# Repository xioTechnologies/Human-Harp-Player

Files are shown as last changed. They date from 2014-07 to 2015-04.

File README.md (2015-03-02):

Human-Harp-Player
=================

The Human Harp Player is a music controller based on interaction with an extendible cord under constant tension.  The Player provides measurements of the cord: extension, velocity, angle (azimuth and elevation) and angular rate (for detecting plucks).  The Player incorporates an [x-OSC](http://www.x-io.co.uk/x-osc/) to interface to host software via Wi-Fi.

Counts vary between 7800 counts/m and 1000 counts/m when fully extended, average = 8900.

See [Human Harp](http://humanharp.org/) for more information about the project.

PCB
---

The PCB was designed in [EAGLE Version 6.6](http://www.cadsoftusa.com/).  It was fabricated by [OSH Park](https://oshpark.com/) and is available to [purchase on their site](https://oshpark.com/shared_projects/F7BSWUvG).

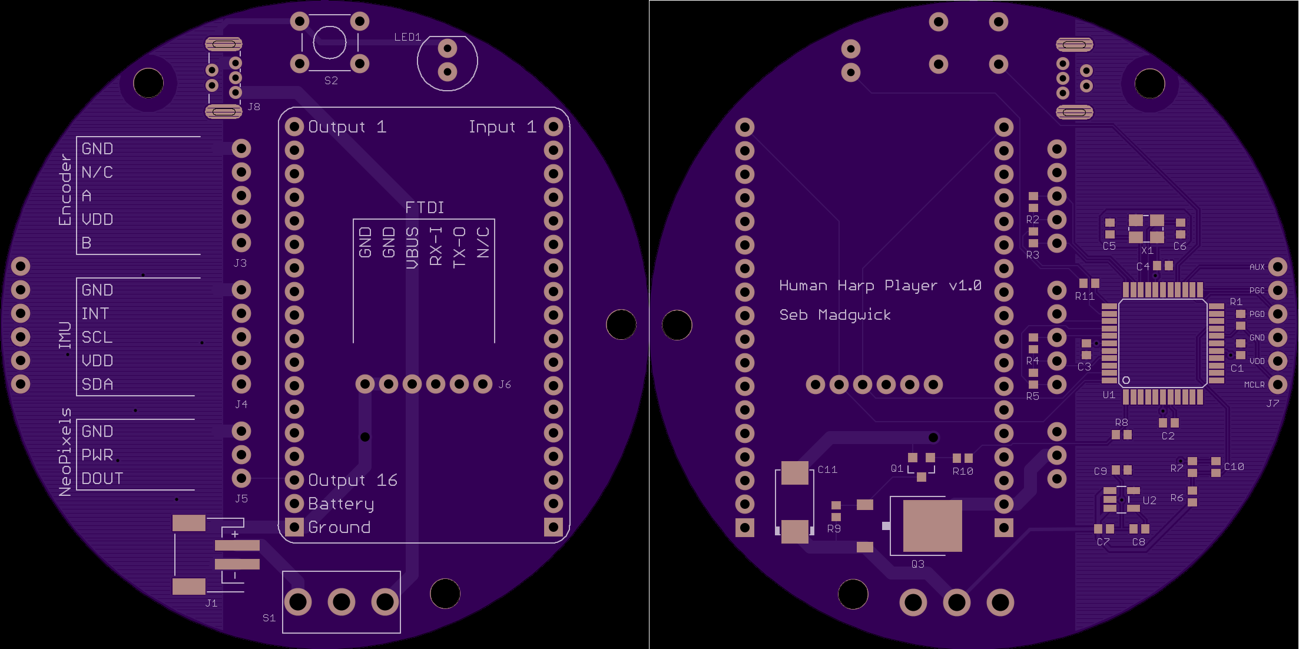
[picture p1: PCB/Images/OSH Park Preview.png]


Firmware
--------

The Human Harp Player uses a Microchip [dsPIC33EP512GM604](http://www.microchip.com/wwwproducts/Devices.aspx?product=dsPIC33EP512GM604) 16-bit [DSC](http://en.wikipedia.org/wiki/Digital_signal_controller) running at 140 MHz (70 MIPS).  The firmware was developed using Microchip's free [MPLABX IDE v2.15](http://www.microchip.com/pagehandler/en-us/family/mplabx/) and [XC16 v1.21 C compiler](http://www.microchip.com/pagehandler/en_us/devtools/mplabxc/).  The PCB incorporates an ICSP header compatible with Microchip programming tools such as the [PICkit 3](http://www.microchip.com/Developmenttools/ProductDetails.aspx?PartNO=PG164130) or [ICD 3](http://www.microchip.com/Developmenttools/ProductDetails.aspx?PartNO=DV164035).

Test App
--------

The Human Harp Player Test App is a cross-platform application for visualising measurement data (distance, velocity, azimuth, elevation and angular rate) in real-time using [Processing](http://www.processing.org/).  Messages from the Player ("Reset", "Zero", "Sleep", "Firmware: vX.X") are displayed in the output console.  Clicking the window sends a 'zero' command.

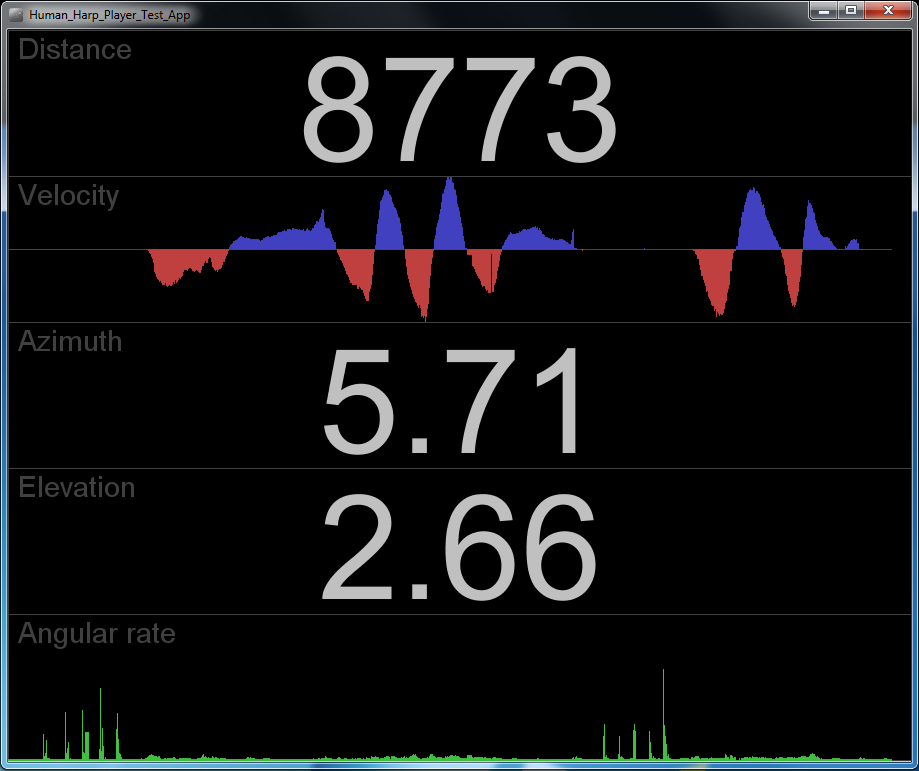
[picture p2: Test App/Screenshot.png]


The Processing sketch requires the [oscP5 library](http://www.sojamo.de/libraries/oscP5/) to send and receive OSC messages.  To use this library, copy the entire *oscP5* directory (.zip available in the repository) into a directory named *"libraries"* in Processing Sketchbook location (see: *File* > *Preferences* > *Sketchbook location*).  A tutorial for sending and receiving OSC messages in Processing is available on the [codasign](http://learning.codasign.com/index.php?title=Sending_and_Receiving_OSC_Data_Using_Processing) website.

**Windows 7 Firewall:**  When running the processing application for the first time you will be prompted to grant network access to Java by Windows Firewall.  Java must be given access "Public" access else network communication will not be possible.  These permission can be modified any time through *Control Panel* > *Windows Firewall* > *"Change settings"*.

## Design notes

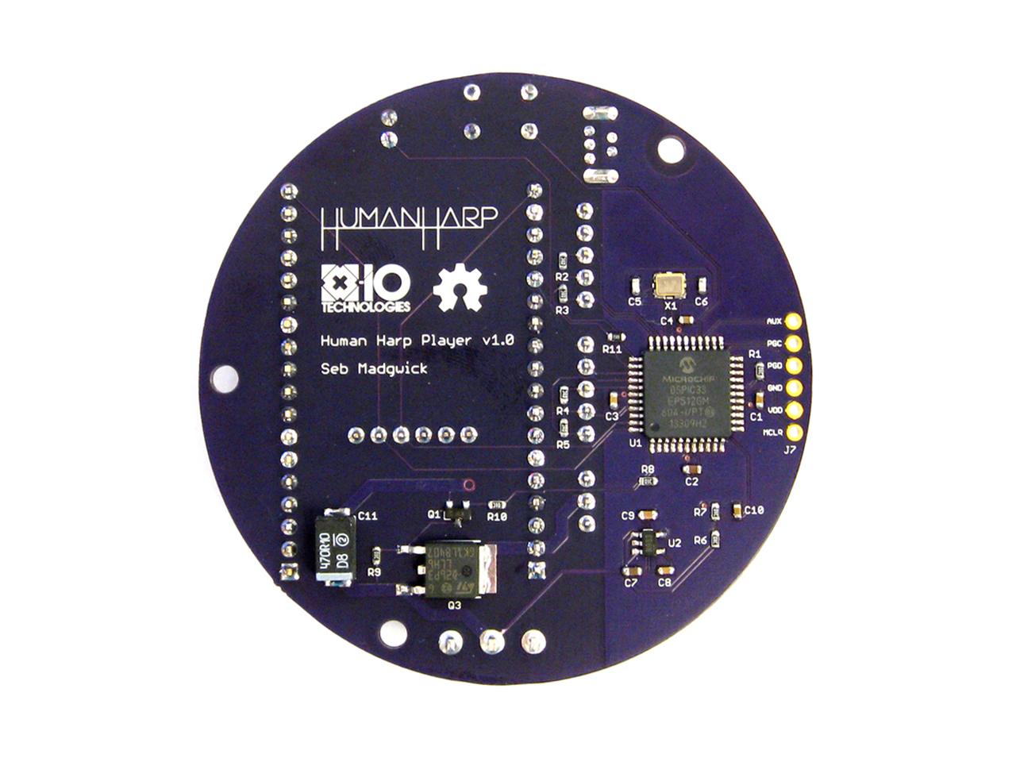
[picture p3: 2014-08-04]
PCB/Images/Photo Bottom.jpg

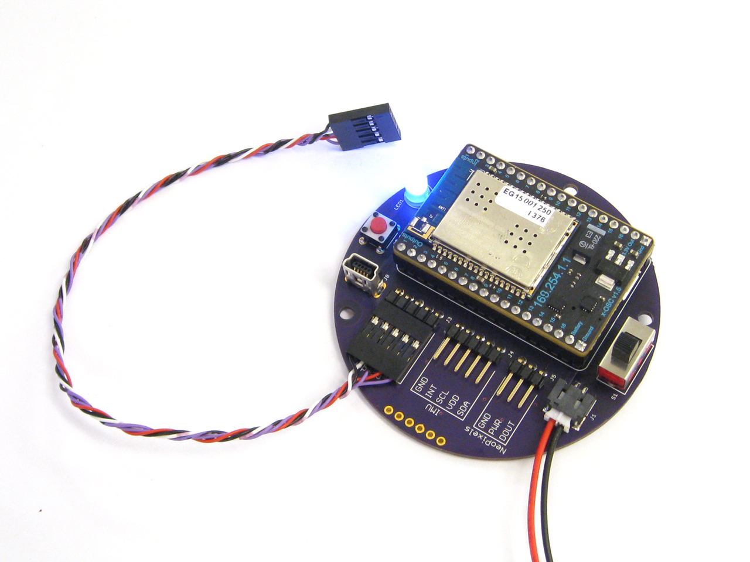
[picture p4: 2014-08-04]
PCB/Images/Photo Connected.jpg

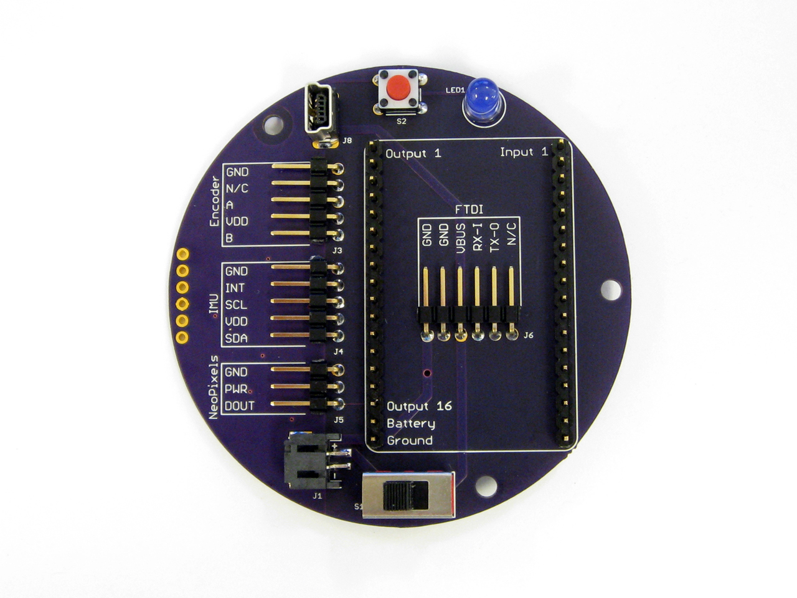
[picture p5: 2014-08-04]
PCB/Images/Photo Top.jpg

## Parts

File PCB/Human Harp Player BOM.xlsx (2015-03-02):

Parts | Qty | Value
C3, C4, C5, C6, C9, C12, C15, C16 | 8 | 100n, 0603
C2, C7, C8, C10, C11 | 5 | 10u, 0603
L1 | 1 | 220u, 510mA, EATON-DRA73-221-R
C13, C14 | 2 | 22p, 0603
C1 | 1 | 470u, 16V, Pansonic F
R1, R2, R3, R4, R5, R6, R7, R8, R9 | 9 | 4k7, 0603
X1 | 1 | ABRACON-ABM8-16.000MHZ-B2-T
U2 | 1 | BMX055
U4 | 1 | DSPIC33EP512GM604-I/PT
U1 | 1 | FT232RL
Q1, Q2 | 2 | IRLML6401PBF
U3 | 1 | MIC5319-3.3YD5
J1 | 1 | Sparkfun-PRT-00587
J3, J5 | 2 | Sparkfun: PRT-00116
J2, J4 | 1 | Unpopulated
U5, U6 | 2 | WS2811

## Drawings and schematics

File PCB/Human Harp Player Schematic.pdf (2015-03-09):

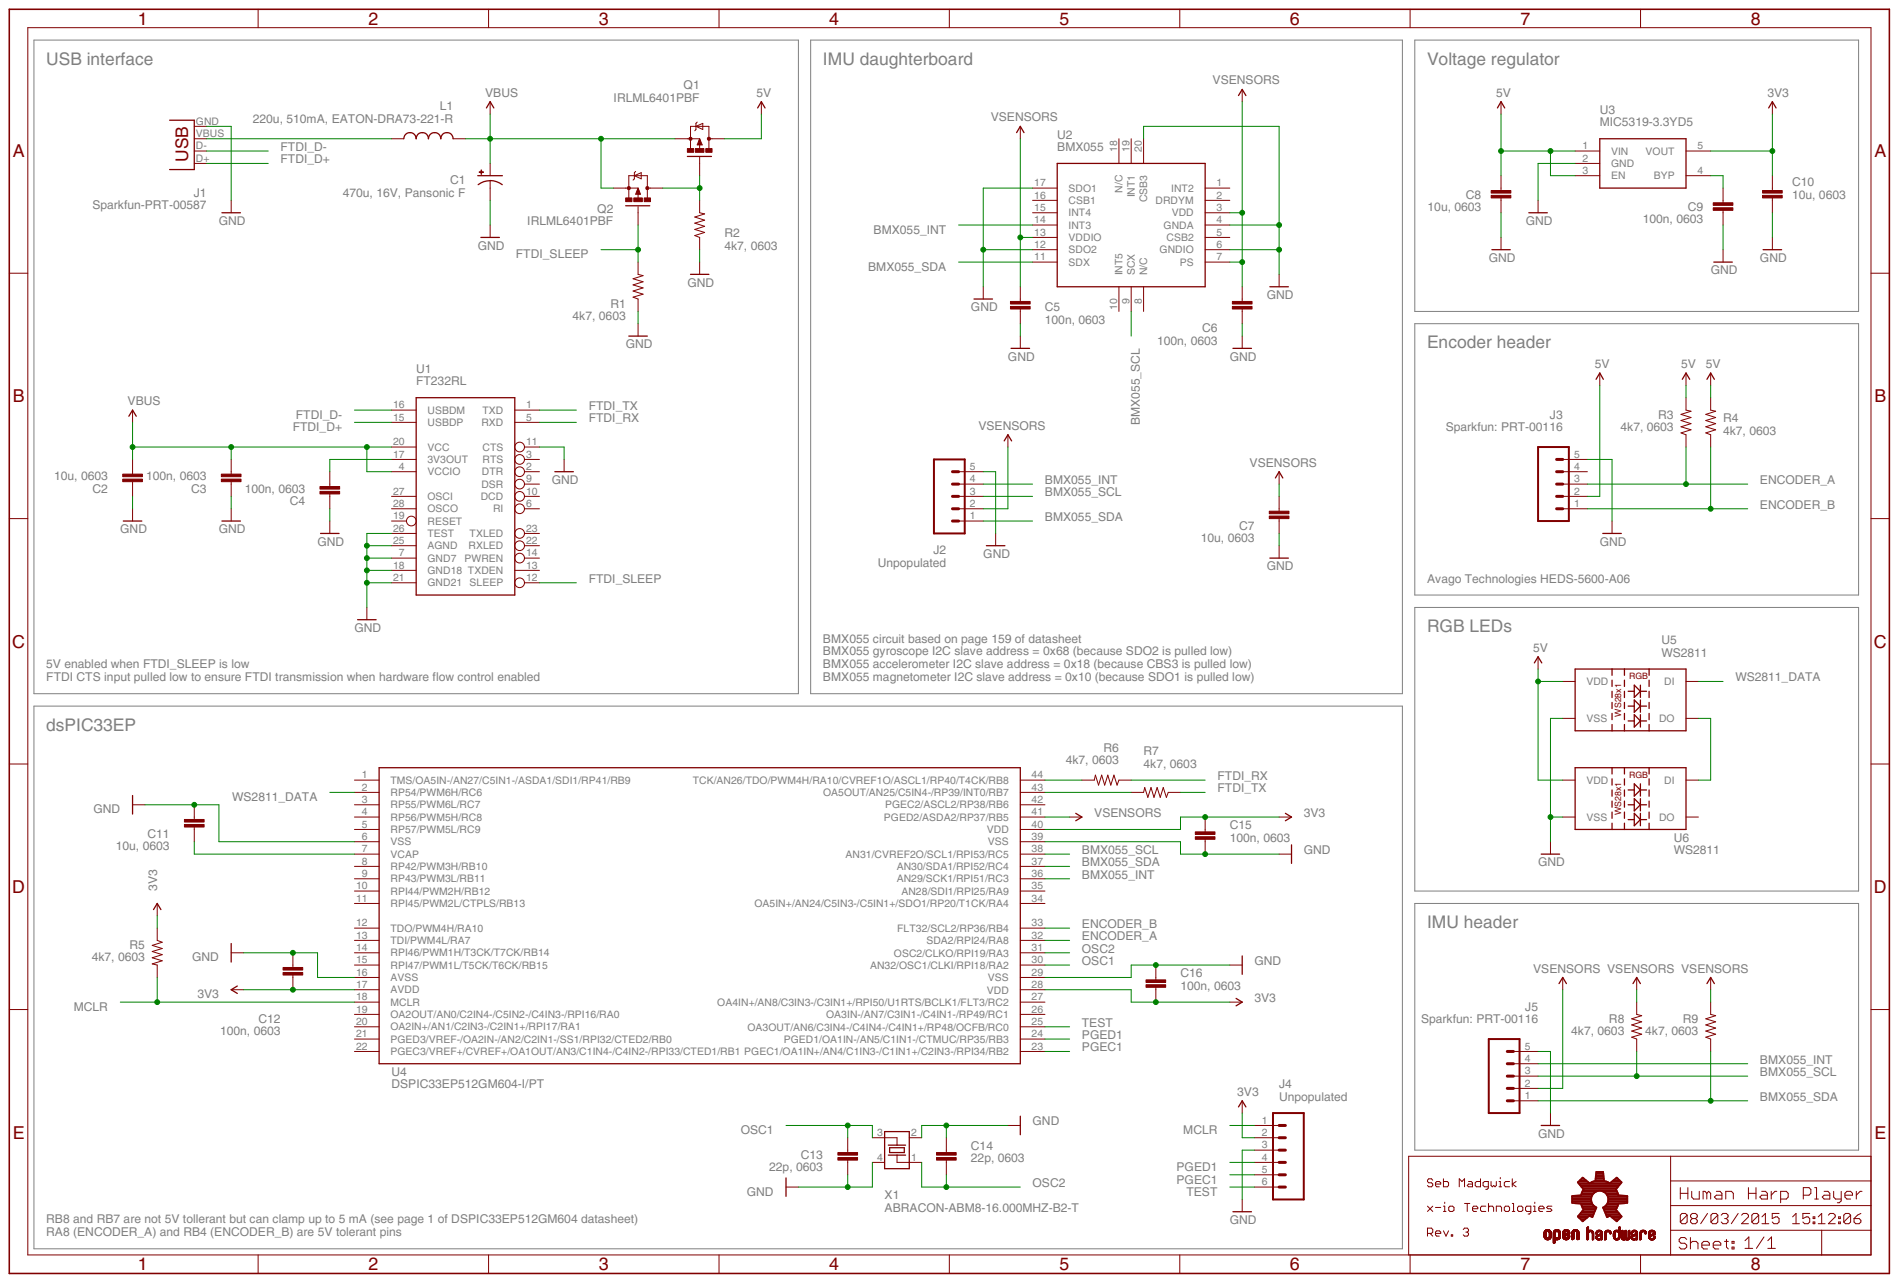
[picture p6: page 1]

Encoder header 5V Avago Technologies HEDS-5600-A06 | 5V 5V

5V enabled when FTDI_SLEEP is low

RB8 and RB7 are not 5V tollerant but can clamp up to 5 mA (see page 1 of DSPIC33EP512GM604 datasheet) RA8 (ENCODER_A) and RB4 (ENCODER_B) are 5V tolerant pins

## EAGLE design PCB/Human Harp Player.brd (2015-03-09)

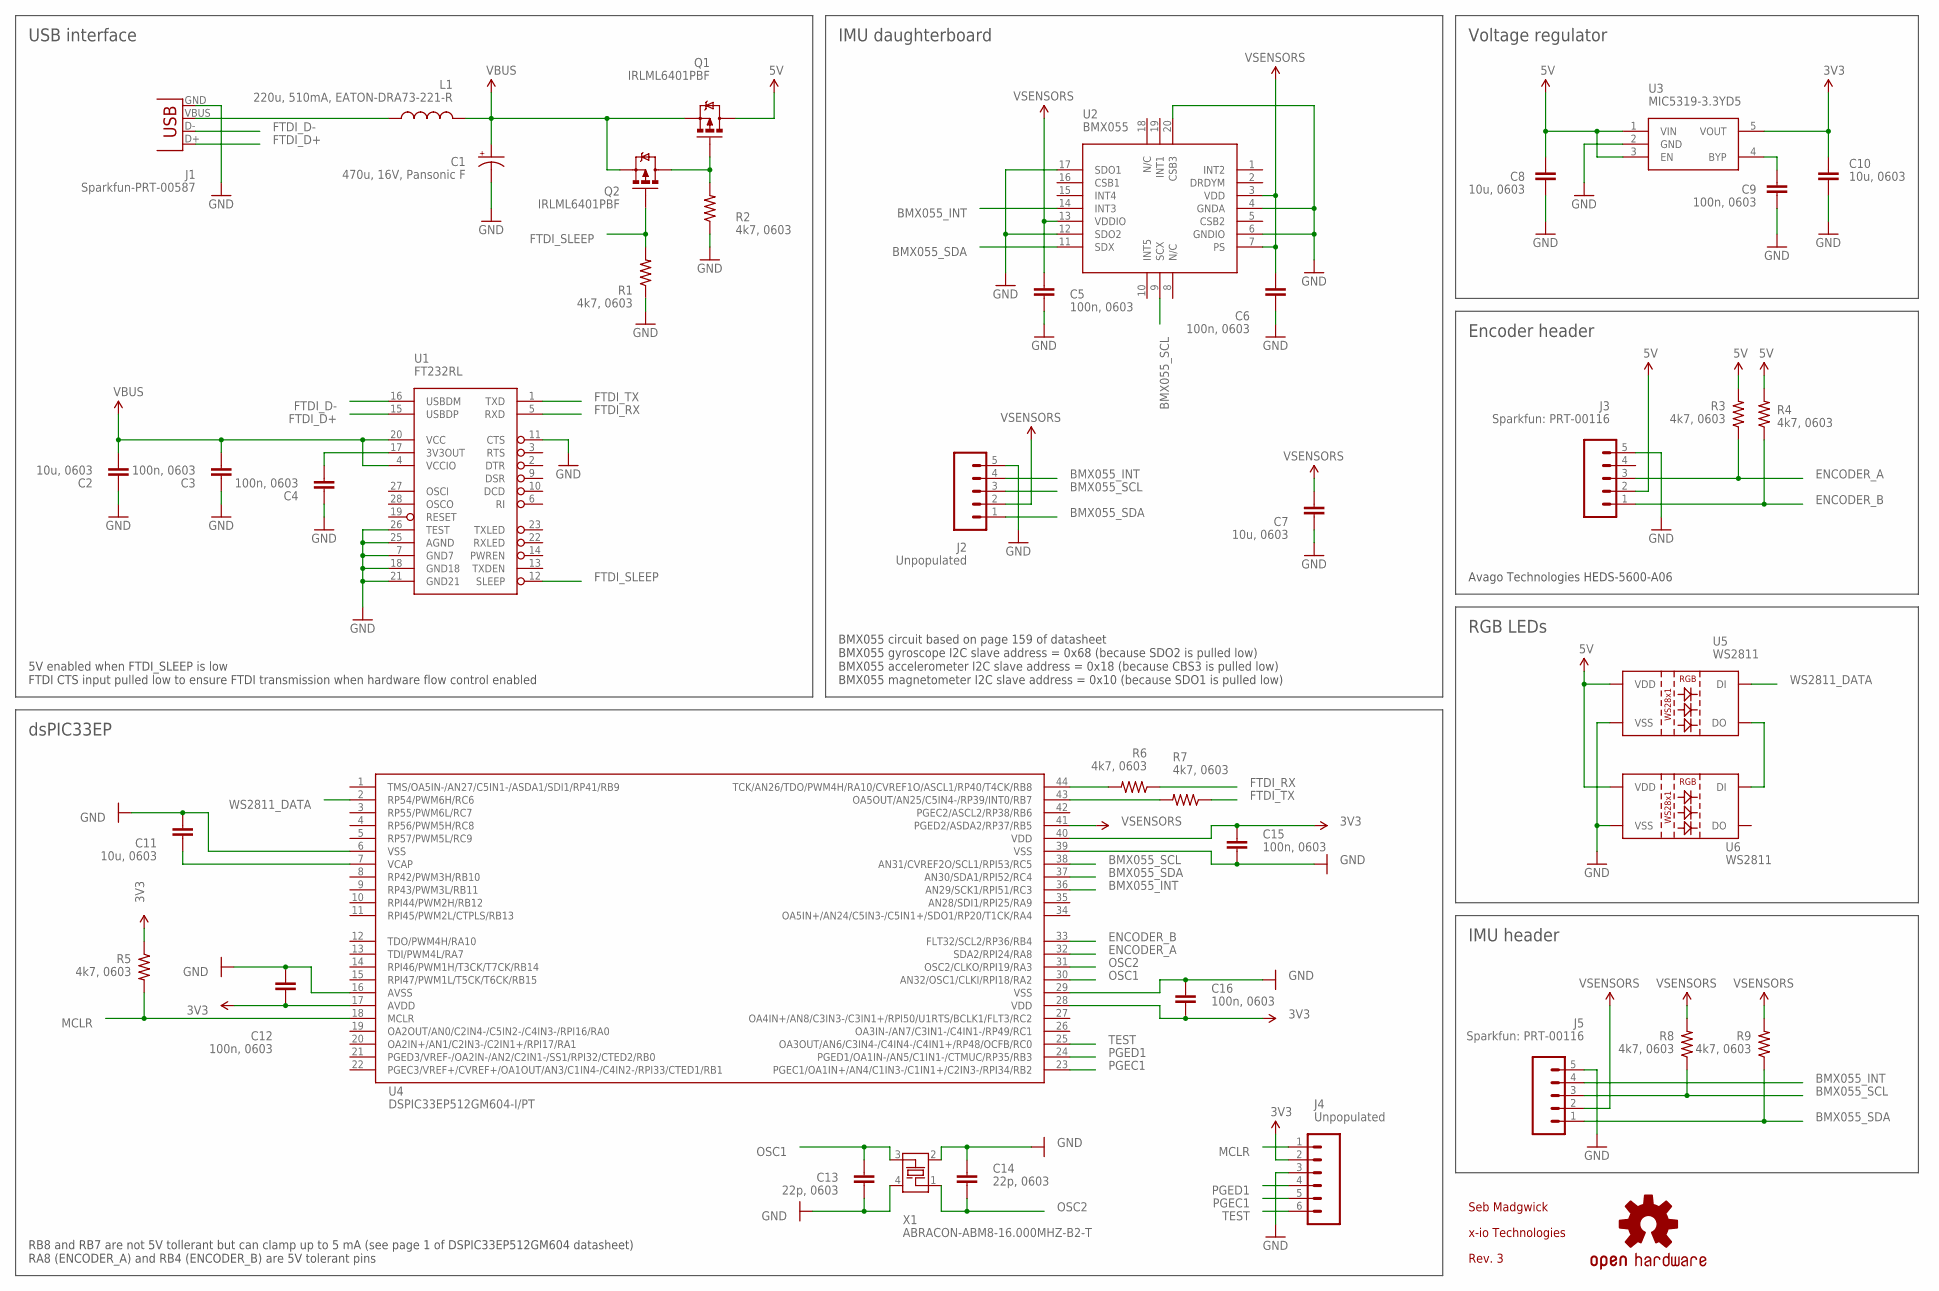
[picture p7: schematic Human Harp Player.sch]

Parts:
C1: 470u, 16V, Pansonic F; PANASONIC_F
C2, C7, C8, C10, C11: 10u, 0603; 0402-CAP
C3, C4, C5, C6, C9, C12, C15, C16: 100n, 0603; 0402-CAP
C13, C14: 22p, 0603; 0402-CAP
J1: Sparkfun-PRT-00587; USB-MINIB
J2: Unpopulated; 1X05
J3, J5: Sparkfun: PRT-00116; 1X05
J4: Unpopulated; 1X06_NO_SILK
L1: 220u, 510mA, EATON-DRA73-221-R; PIS2816
LOGO1: OSHW-LOGOL; OSHW-LOGO-L
Q1, Q2: IRLML6401PBF; SOT23-3
R1, R2, R3, R4, R5, R6, R7, R8, R9: 4k7, 0603; 0402-RES
U1: FT232RL; SSOP28DB
U2: BMX055
U3: MIC5319-3.3YD5; SOT23-5
U4: DSPIC33EP512GM604-I/PT; TQFP44
U5, U6: WS2811; LED-TRICOLOR-5050-IC
X1: ABRACON-ABM8-16.000MHZ-B2-T; ABM8

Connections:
3V3: C10.1, C12.1, C15.1, C16.2, J4.2, R5.1, U3.5 (VOUT), U4.17 (AVDD), U4.28 (VDD), U4.40 (VDD)
5V: C8.1, J3.2, Q1.3 (D), R3.2, R4.2, U3.1 (VIN), U3.3 (EN), U5.3 (VDD), U5.5 (VDD), U6.3 (VDD), U6.5 (VDD)
BMX055_INT: J2.4, J5.4, U2.14 (INT3), U4.36 (AN29/SCK1/RPI51/RC3)
BMX055_SCL: J2.3, J5.3, R8.1, U2.9 (SCX), U4.38 (AN31/CVREF2O/SCL1/RPI53/RC5)
BMX055_SDA: J2.1, J5.1, R9.1, U2.11 (SDX), U4.37 (AN30/SDA1/RPI52/RC4)
ENCODER_A: J3.3, R3.1, U4.32 (SDA2/RPI24/RA8)
ENCODER_B: J3.1, R4.1, U4.33 (FLT32/SCL2/RP36/RB4)
FTDI_D+: J1.D+, U1.15 (USBDP)
FTDI_D-: J1.D-, U1.16 (USBDM)
FTDI_RX: R6.1, U1.5 (RXD)
FTDI_SLEEP: Q2.1 (G), R1.2, U1.12 (SLEEP)
FTDI_TX: R7.1, U1.1 (TXD)
GND: C1.-, C2.1, C3.1, C4.1, C5.2, C6.2, C7.1, C8.2, C9.2, C10.2, C11.2, C12.2, C13.1, C14.1, C15.2, C16.1, J1.GND, J2.5, J3.5, J4.3, J5.5, R1.1, R2.1, U1.7 (GND7), U1.11 (CTS), U1.18 (GND18), U1.21 (GND21), U1.25 (AGND), U1.26 (TEST), U2.4 (GNDA), U2.6 (GNDIO), U2.12 (SDO2), U2.17 (SDO1), U2.20 (CSB3), U3.2 (GND), U4.6 (VSS), U4.16 (AVSS), U4.29 (VSS), U4.39 (VSS), U5.6 (VSS), U6.6 (VSS), X1.2, X1.4
MCLR: J4.1, R5.2, U4.18 (MCLR)
unnamed: Q1.1 (G), Q2.3 (D), R2.2
unnamed: R6.2, U4.44 (TCK/AN26/TDO/PWM4H/RA10/CVREF1O/ASCL1/R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)
unnamed: C4.2, U1.17 (3V3OUT)
unnamed: C11.1, U4.7 (VCAP)
unnamed: R7.2, U4.43 (OA5OUT/AN25/C5IN4-/RP39/INT0/RB7)
unnamed: J1.VBUS, L1.1
unnamed: C9.1, U3.4 (BYP)
unnamed: U5.1 (DO), U6.2 (DI)
OSC1: C13.2, U4.30 (AN32/OSC1/CLKI/RPI18/RA2), X1.3
OSC2: C14.2, U4.31 (OSC2/CLKO/RPI19/RA3), X1.1
PGEC1: J4.5, U4.23 (PGEC1/OA1IN+/AN4/C1IN3-/C1IN1+/C2IN3-/R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)
PGED1: J4.4, U4.24 (PGED1/OA1IN-/AN5/C1IN1-/CTMUC/RP35/RB3)
TEST: J4.6, U4.25 (OA3OUT/AN6/C3IN4-/C4IN4-/C4IN1+/RP48/OC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)
VBUS: C1.+, C2.2, C3.2, L1.2, Q1.2 (S), Q2.2 (S), U1.4 (VCCIO), U1.20 (VCC)
VSENSORS: C5.1, C6.1, C7.2, J2.2, J5.2, R8.2, R9.2, U2.3 (VDD), U2.7 (PS), U2.13 (VDDIO), U4.41 (PGED2/ASDA2/RP37/RB5)
WS2811_DATA: U4.2 (RP54/PWM6H/RC6), U5.2 (DI)

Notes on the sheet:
Voltage regulator
Seb Madgwick
x-io Technologies
dsPIC33EP
Encoder header
IMU header
IMU daughterboard
USB interface
Avago Technologies HEDS-5600-A06
5V enabled when FTDI_SLEEP is low FTDI CTS input pulled low to ensure FTDI transmission when hardware flow control enabled
BMX055 circuit based on page 159 of datasheet BMX055 gyroscope I2C slave address = 0x68 (because SDO2 is pulled low) BMX055 accelerometer I2C slave address = 0x18 (because CBS3 is pulled low) BMX055 magnetometer I2C slave address = 0x10 (because SDO1 is pulled low)
RGB LEDs
RB8 and RB7 are not 5V tollerant but can clamp up to 5 mA (see page 1 of DSPIC33EP512GM604 datasheet) RA8 (ENCODER_A) and RB4 (ENCODER_B) are 5V tolerant pins
Rev. 3

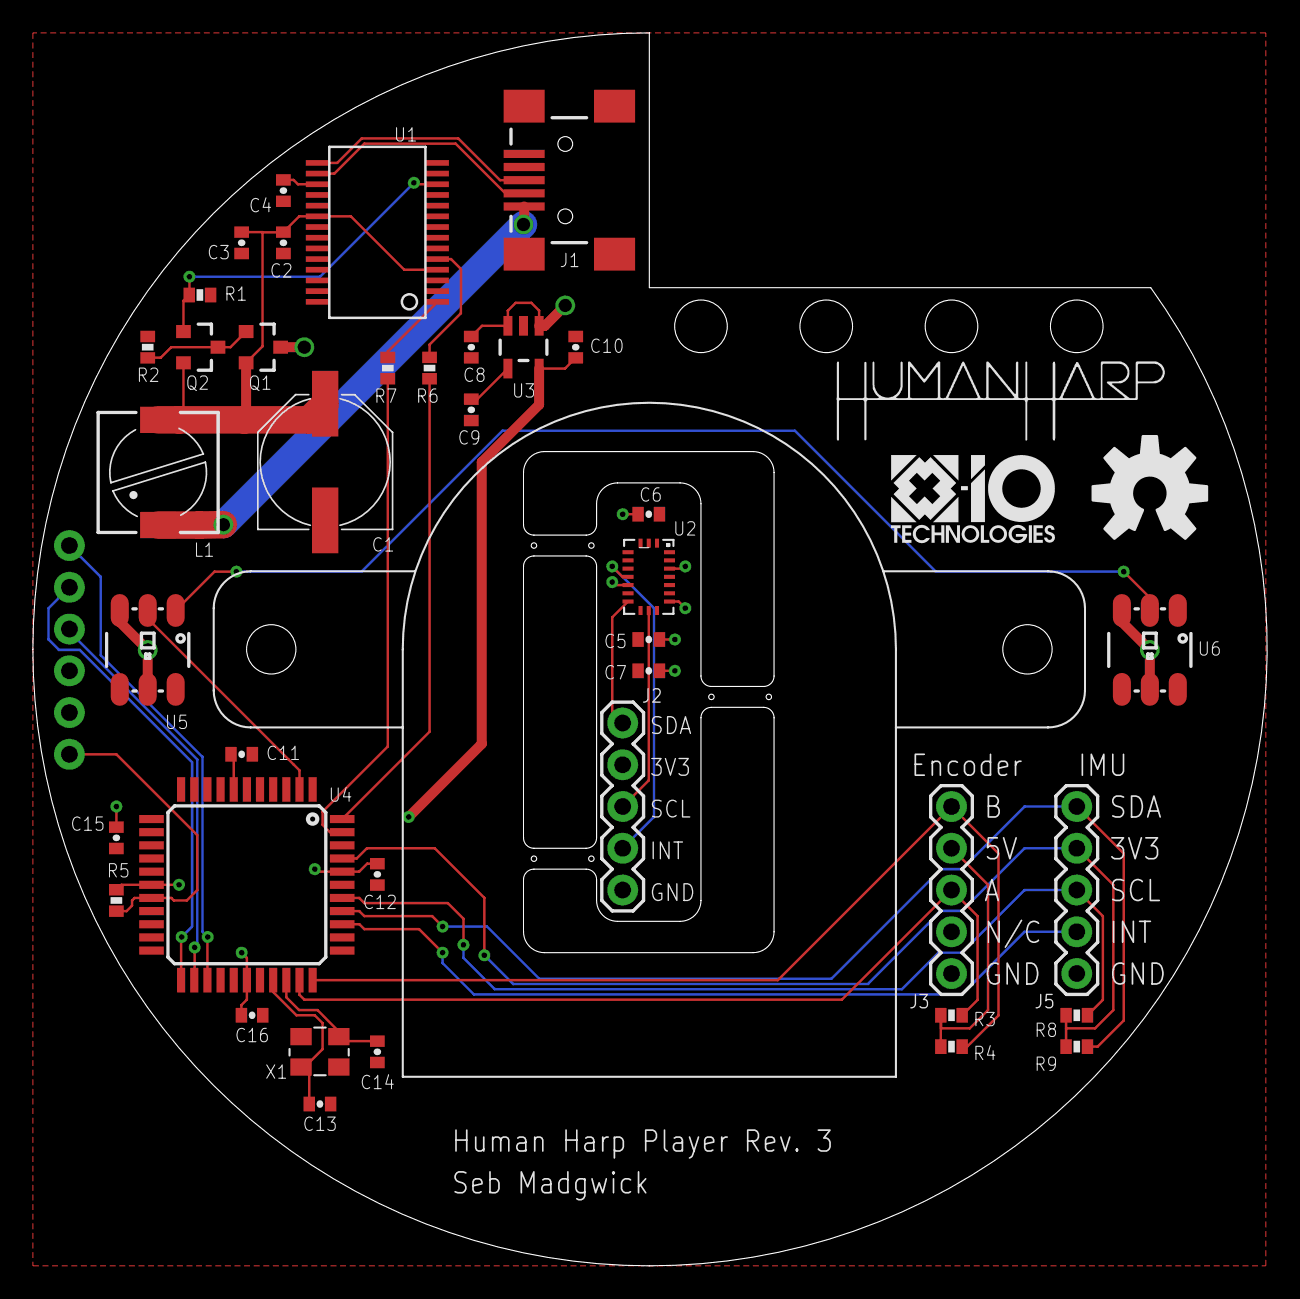
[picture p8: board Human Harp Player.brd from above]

Board: 2 copper layers, 75.1 x 75.0 mm, 44 parts (0 on the bottom side), 30 nets.

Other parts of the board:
U$1: X-IO_TECHNOLOGIES_LOGO_10MM_TOP
U$2: HEDS-5600-A06
U$4: HUMAN_HARP_LOGO_20MM_TOP

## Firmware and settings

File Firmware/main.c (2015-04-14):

/*
 * @file Main.h
 * @author Seb Madgwick
 *
 * Device:
 * dsPIC33EP512GM604
 *
 * Compiler:
 * MPLAB XC16 v1.24
 *
 * Peripherals used:
 * INT1                 Imu.c
 * Timer 4,5            Timer.c
 * QEI1                 Encoder.c
 * I2C1                 I2C1.c
 * UART1                Uart1.c
 *
 * Interrupt priorities (nesting enabled):
 * 7.
 * 6.
 * 5. TMR5 (Timer.c)
 * 4. I2C1 (I2C1.c)
 * 3. INT1 (Imu.c)
 * 2. UART1 (Uart1.c)
 * 1.
 */

//------------------------------------------------------------------------------
// Includes

#include "Encoder/Encoder.h"
#include "Imu/Imu.h"
#include "Receive/Receive.h"
#include "Send/Send.h"
#include <stdbool.h>
#include "SystemDefinitions.h"
#include "Timer/Timer.h"
#include "Uart/Uart1.h"
#include <xc.h>

//------------------------------------------------------------------------------
// Configuration Bits

_FICD(JTAGEN_OFF); // JTAG is disabled
_FWDT(FWDTEN_OFF); // Watchdog timer enabled/disabled by user software
_FOSC(FCKSM_CSECMD & POSCMD_HS); // Clock switching is enabled,Fail-safe Clock Monitor is disabled; HS Crystal Oscillator Mode
_FOSCSEL(FNOSC_FRC & IESO_OFF); // Internal Fast RC (FRC); Start up with user-selected oscillator source

//------------------------------------------------------------------------------
// Function prototypes

static void Initialise(void);

//------------------------------------------------------------------------------
// Functions

/**
 * @brief Firmware entry point.
 * @return This function should never return.
 */
int main(void) {

    // Initialise oscillator and I/O
    Initialise();

    // Initialise drivers and middleware modules
    TimerInitialise();
    EncoderInitialise();
    ImuInitialise();
    const UartSettings uartSettings = DEFAULT_UART_SETTINGS;
    Uart1Initialise(&uartSettings);

    // Start up application tasks
    SendReset();
    SendFirmwareVersion();

    // Main loop
    while (true) {

        // Application tasks
        SendDoTasks();
        ReceiveDoTasks();
    }
}

/**
 * @brief Initialise oscillator and I/O.
 */
static void Initialise(void) {

    // Configure oscillator for 70 MIPS with 16 MHz external crystal
    PLLFBD = 33; // M = 35
    CLKDIVbits.PLLPOST = 0; // N2 = 2
    CLKDIVbits.PLLPRE = 0; // N1 = 2
    __builtin_write_OSCCONH(0x03); // initiate Clock Switch to Primary Oscillator with PLL (NOSC=0b011)
    __builtin_write_OSCCONL(OSCCON | 0x01);
    while (OSCCONbits.COSC != 0b011); // wait for Clock switch to occur
    while (OSCCONbits.LOCK != 1); // wait for PLL to lock

    // Disable analogue inputs
    ANSELA = 0x0000;
    ANSELB = 0x0000;
    ANSELC = 0x0000;

    // Configure encoder I/O
    ENCODER_A_MAP();
    ENCODER_B_MAP();

    // Configure IMU I/O
    IMU_VDD_LAT = 0;
    IMU_VDD_TRIS = 0;
    IMU_INT_MAP();

    // Configure UART I/O
    UART_RX_MAP();
    UART_TX_MAP();

    // Configure Test pin I/O
    TEST_TRIS = 0;
}

//------------------------------------------------------------------------------
// End of file

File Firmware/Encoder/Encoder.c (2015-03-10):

/*
 * @file Encoder.c
 * @author Seb Madgwick
 * @brief Quadrature encoder module to provide measurements of rotational
 * position and velocity.
 */

//------------------------------------------------------------------------------
// Includes

#include "Encoder.h"
#include "SystemDefinitions.h" // FCY
#include <xc.h>

//------------------------------------------------------------------------------
// Definitions

/**
 * @brief Int32 union typedef.
 */
typedef union {
    int32_t value;

    struct {
        uint16_t word0;
        uint16_t word1;
    };
} Int32Union;

//------------------------------------------------------------------------------
// Functions

/**
 * @brief Initialises module.  This function should be called once on system
 * start up.
 */
void EncoderInitialise() {
    QEI1CONbits.QEIEN = 1; // Module counters are enabled
}

/**
 * @brief Gets current rotational position measurement.
 * @return Current rotational position measurement.
 */
int32_t EncoderGetPostion() {
    Int32Union position;
    position.word0 = POS1CNTL;
    position.word1 = POS1HLD;
    return position.value;
}

/**
 * @brief Gets current rotational velocity measurement.
 * @return Current rotational velocity measurement.
 */
int32_t EncoderGetVelocity() {

    // Read registers 'simultaneously'
    asm volatile("DISI #3"); // disable all interrupts (except level 7) for 3 instructions
    Int32Union interval;
    interval.word0 = INT1HLDL;
    interval.word1 = INT1HLDH;
    const int16_t velocityCoutner = VEL1CNT;

    // Store direction
    float direction;
    if (velocityCoutner > 0) {
        direction = 1.0f;
    } else if (velocityCoutner < 0) {
        direction = -1.0f;
    } else {
        return 0;
    }

    // Calculate velocity with rounding
    return (int32_t) ((direction * (float) (FCY << 1) / (float) interval.value) + 0.5f);
}

/**
 * @brief Zeros rotational position measurement.
 */
void EncoderZero() {
    POS1HLD = 0;
    POS1CNTL = 0;
}

//------------------------------------------------------------------------------
// End of file

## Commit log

2014-07-18 Commit PCB project files
    [Human Harp Player.brd, Human Harp Player.sch]
2014-07-23 Remove code artifacts in encoder initialisation
2014-07-23 Fix bug that causes infinite loop just before sleep
    [Imu.c, main.c]
2014-07-24 Switch encoder A/B signals in firmware
2014-07-24 Reduce send rate to 50 Hz
2014-07-25 Test App indicates battery voltage
2014-08-04 Add PCB photos
2015-03-02 Commit PCB Rev. 2
    [Human Harp Player BOM.xlsx, Human Harp Player.brd, Human Harp Player.sch]
2015-03-09 Add missing VDD connection to ICSP and XYZ label on PCB
    [Human Harp Player.brd, Human Harp Player.sch]
2015-03-09 Remove unused code from Firmware for PCB Rev. 2
2015-03-09 Use latest UART library an implement RX commands
2015-03-09 Use latest I2C library
2015-03-09 Use latest Timer library
2015-03-10 Tidy up Encoder, IMU, Send and Receive modules
2015-04-14 Fix I2C ACK/NACK bug and use latest compiler
    [main.c]

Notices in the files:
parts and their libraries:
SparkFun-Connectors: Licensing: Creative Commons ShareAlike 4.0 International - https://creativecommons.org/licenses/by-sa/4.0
